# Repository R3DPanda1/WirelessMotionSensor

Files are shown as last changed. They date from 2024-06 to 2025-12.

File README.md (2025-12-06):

# Wireless Motion Sensor

A portable all-in-one motion sensor device with Bluetooth connectivity and SD card data logging capabilities, developed as a Bachelor's thesis project at UAS Technikum Wien.

## Overview

This project presents a low-cost, user-friendly wireless motion tracking device designed for measuring acceleration, rotation, and orientation data at 100 Hz using a Bosch BNO055 IMU sensor. The device features wireless communication between two units, local data storage, and an intuitive OLED display interface.

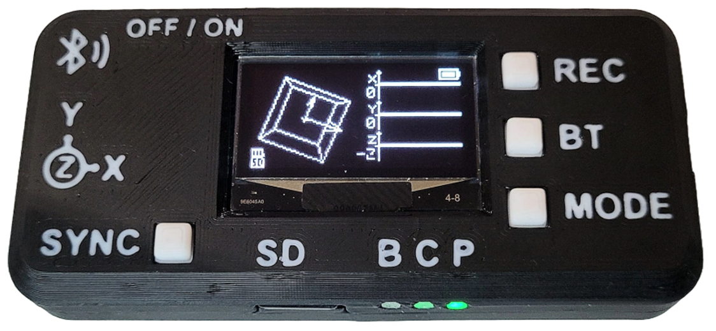
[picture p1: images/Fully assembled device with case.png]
Fully Assembled Device


## Key Features

- **High-Speed Motion Capture**: Measures acceleration, rotation, and orientation at 100 Hz
- **Wireless Communication**: Bluetooth Classic connectivity for real-time data sharing between two devices
- **Data Logging**: SD card storage in CSV format for easy data access
- **Clock Synchronization**: Devices can be synchronized by tapping them together (high-g interrupt method)
- **User-Friendly Interface**: 1.3" OLED display with push-button controls
- **Portable Design**: Battery-powered with 3D-printed snap-fit case
- **Multiple Operation Modes**:
  - Fusion Mode (orientation visualization)
  - Temperature Mode
  - Spirit Level Mode
  - Raw Readings Mode

## Hardware Components

### Main Components
- **Microcontroller**: ESP32-WROOM-32
- **IMU Sensor**: Bosch BNO055 (9-DOF with sensor fusion)
- **Display**: SH1106 1.3" OLED (128x64 pixels)
- **Storage**: MicroSD card slot
- **Power**: Li-Ion/Li-Polymer battery with USB-C charging
- **Connectivity**: Bluetooth Classic

### PCB Design

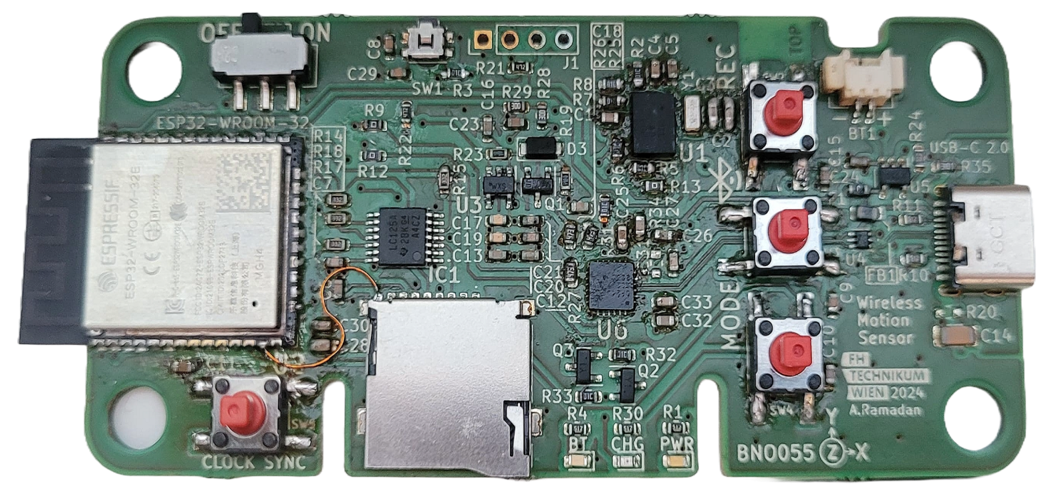
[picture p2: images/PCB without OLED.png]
PCB without OLED

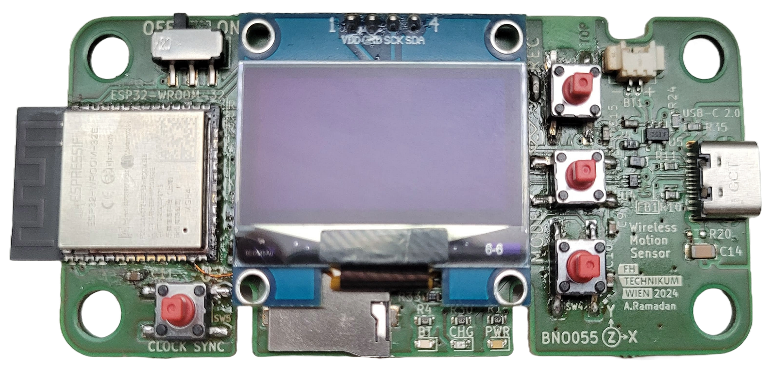
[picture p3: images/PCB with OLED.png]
PCB with OLED


The custom 4-layer PCB features:
- Compact design (96.6mm x 44.4mm x 19.9mm)
- Hand-assembled components
- Compatible with various 0.96" or 1.3" OLED displays
- M5 mounting holes for case integration

### Circuit Schematic

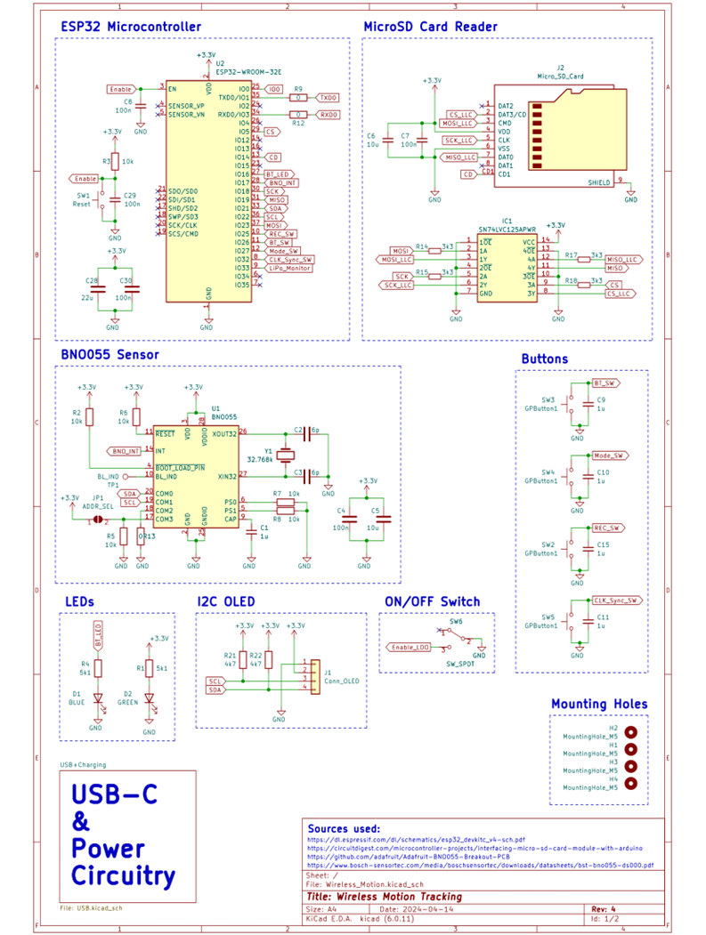
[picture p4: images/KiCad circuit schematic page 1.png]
Circuit Schematic Page 1

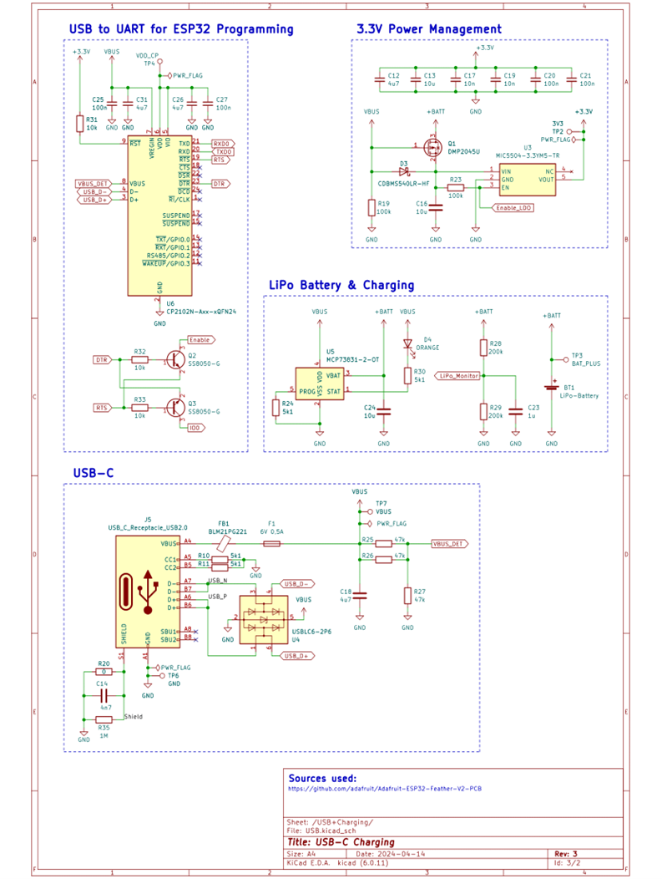
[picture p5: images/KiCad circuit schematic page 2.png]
Circuit Schematic Page 2


## Case Design

The device is housed in a 3D-printed snap-fit case designed in Autodesk Fusion:

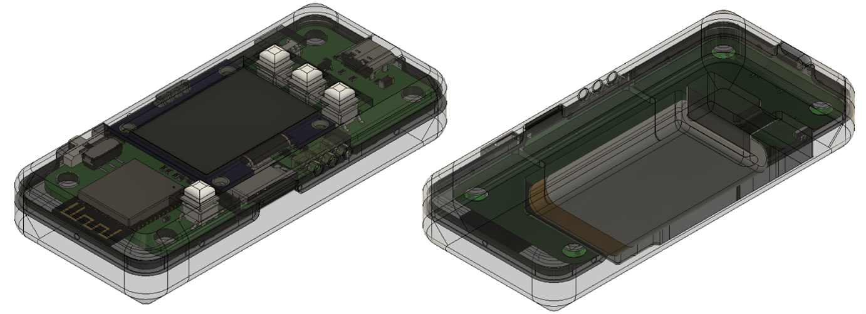
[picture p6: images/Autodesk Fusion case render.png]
Case Render


Features:
- Snap-fit assembly (no screws required)
- Integrated battery compartment
- Button and switch caps
- Multi-material printing support for labeling

## Software Architecture

The firmware uses FreeRTOS with seven concurrent tasks:
- **Button Task**: Handles user input
- **Sensor Task**: Reads IMU data and manages clock synchronization
- **Render Task**: Controls OLED display output
- **Bluetooth TX/RX Tasks**: Manages wireless communication
- **SD Card Task**: Handles file operations
- **CSV Task**: Prepares data for logging with write buffer optimization

### Data Recording

- CSV format for easy accessibility
- Buffered writing to reduce SD card wear
- Simultaneous local and remote data logging
- Timestamp synchronization between devices

## Operation Modes

1. **Fusion Mode**: 3D cube visualization of orientation with linear acceleration graph
2. **Temperature Mode**: Display local and remote temperature readings
3. **Spirit Level Mode**: Digital level indicator with tilt angle
4. **Raw Readings Mode**: Real-time graphs of accelerometer, gyroscope, and magnetometer data
5. **Clock Sync Mode**: Synchronize device clocks by tapping them together

## Getting Started

### Hardware Requirements
- Wireless Motion Sensor device
- MicroSD card (formatted as FAT32)
- Li-Ion or Li-Polymer battery (JST 2.54mm connector)
- USB-C cable for charging and programming

### Basic Usage

1. **Power On**: Slide the ON/OFF switch to ON position
2. **Insert SD Card**: Insert a FAT32-formatted microSD card (optional, for data logging)
3. **Connect Devices**: Press the BT button on one device to establish connection
4. **Select Mode**: Press MODE button to cycle through operation modes
5. **Record Data**: Press REC button to start/stop data logging
6. **Sync Clocks**: Press SYNC button (on master device) and tap devices together

### Controls

- **MODE**: Switch between operation modes
- **BT**: Initiate/disconnect Bluetooth connection
- **REC**: Start/stop CSV data logging
- **SYNC**: Begin clock synchronization process (master device only)

## Performance

- **Synchronization Accuracy**: Typically within 5ms
- **Bluetooth Latency**: ~15ms average
- **Data Rate**: 100 Hz for all sensor readings
- **Packet Loss**: ~24% during simultaneous Bluetooth and SD card operations

## Applications

- Motion capture and tracking
- Sports performance analysis
- Gait analysis and rehabilitation
- Robotics and drone motion tracking
- Joint movement studies
- Vibration analysis

## Development

### Build Environment
- Platform: PlatformIO with Arduino framework
- Language: C/C++
- RTOS: FreeRTOS

### PCB Design
- Tool: KiCad
- Manufacturer: Aisler
- Layers: 4 (Signal, Ground, Power, Signal)

### Mechanical Design
- Tool: Autodesk Fusion
- Manufacturing: 3D printing (FDM)

## Project Structure

```
WirelessMotionSensor/
├── src/                    # Source code
├── include/                # Header files
├── KiCad/                  # PCB design files
├── CAD/                    # 3D case design files
├── images/                 # Documentation images
└── platformio.ini          # PlatformIO configuration
```

## Future Improvements

- Enhanced communication protocol (ESP-NOW) for multiple device support
- Optimized code for better performance
- Additional display interfaces
- Live data logging over USB
- Support for more than two connected devices

## License

This project was developed as a Bachelor's thesis at UAS Technikum Wien.

## Author

**Alper Ramadan**
Bachelor of Science in Engineering - Electronics
UAS Technikum Wien, 2024

Supervisor: Stefan Paschek, MSc

## Acknowledgments

Special thanks to:
- UAS Technikum Wien for providing education and resources
- Jakob Frenzel for PCB design guidance
- Adafruit and AZ-Delivery for open-source hardware designs

## References

Based on the Bachelor's thesis: "Development of a Portable Motion Sensor Device with Bluetooth and SD Card Capabilities"

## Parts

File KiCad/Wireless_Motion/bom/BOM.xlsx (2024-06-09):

Bill of Materials for Two Devices
Mouser Parts
Designator | Value | Footprint | Mouser Part Number | Order Unit Price | Quantity | Total
BT1 | LiPo-Battery | JST 1x02 | 538-53261-0271 | €0.409 | 2 | €0.818
C1,C9,C10,C11,C15,C23 | 1u | 0603 - Inch | 80-C0603C105K4R | €0.039 | 12 | €0.468
C12,C18,C26,C31 | 4u7 | 0603 - Inch | 187-CL10A475KQ8NNNC | €0.094 | 8 | €0.752
C14 | 4n7 | 1206 - Inch | 80-C1206C472K5R7553 | €0.093 | 2 | €0.186
C17,C19 | 10n | 0603 - Inch | 581-06031C103K | €0.094 | 4 | €0.376
C2,C3 | 6p | 0603 - Inch | 80-CBR06C609C5GAUTO | €0.093 | 4 | €0.372
C28 | 22u | 0603 - Inch | 81-GRM188R60J226ME0D | €0.140 | 2 | €0.280
C4,C7,C8,C20,C21,C25,C27,C29,C30 | 100n | 0603 - Inch | 80-C0603C104J5R | €0.051 | 18 | €0.918
C5,C6,C13,C16,C24 | 10u | 0603 - Inch | 187-CL10A106MQ8NNNC | €0.067 | 10 | €0.670
D1 | BLUE | 0603 - Inch | 720-LBQ39GL2N2351 | €0.338 | 2 | €0.676
D2 | GREEN | 0603 - Inch | 720-LTQ39GQ1S22515 | €0.338 | 2 | €0.676
D3 | CDBMS540LR-HF | SOD-123 | 750-CDBMS540LR-HF | €0.363 | 2 | €0.726
D4 | ORANGE | 0603 - Inch | 720-LYQ396P1Q236 | €0.205 | 2 | €0.410
F1 | 6V 0,5A | 0603 - Inch | 603-SMD0603B050TF | €0.188 | 2 | €0.376
FB1 | BLM21PG221 | 0805 - Inch | 81-BLM21P221SG | €0.112 | 2 | €0.224
IC1 | SN74LVC125APWR | SN74LVC125APWR | 595-SN74LVC125APWR | €0.372 | 2 | €0.744
J2 | Micro_SD_Card | Micro SD card connector | 909-MICRO-SD-CARD | €0.512 | 2 | €1.024
J5 | USB_C_Receptacle_USB2.0 | GCT USB4105-xx-A 16P | 640-USB4105-GF-A | €0.752 | 2 | €1.504
Q1 | DMP2045U | SOT-23-3 | 621-DMP2045U-7 | €0.363 | 2 | €0.726
Q2,Q3 | SS8050-G | Package_TO_SOT_SMD:SOT-23 | 750-SS8050-G | €0.130 | 4 | €0.520
R1,R4,R10,R11,R24,R30 | 5k1 | 0603 - Inch | 708-RMCF0603FT5K10 | €0.094 | 12 | €1.128
R14,R15,R17,R18 | 3k3 | 0603 - Inch | 754-RG1608P-332DT5 | €0.093 | 8 | €0.744
R19,R23 | 100k | 0603 - Inch | 667-ERJ-3EKF1003V | €0.094 | 4 | €0.376
R2,R3,R5,R6,R7,R8,R31,R32,R33 | 10k | 0603 - Inch | 603-RT0603FRE0710KL | €0.052 | 18 | €0.936
R21,R22 | 4k7 | 0603 - Inch | 652-CR0603-JW-472ELF | €0.011 | 4 | €0.044
R25,R26,R27 | 47k | 0603 - Inch | 603-RT0603FRE1347RL | €0.093 | 6 | €0.558
R28,R29 | 200k | 0603 - Inch | 603-RC0603FR-07200KL | €0.093 | 4 | €0.372
R35 | 1M | 0603 - Inch | 603-RC0603FR-071ML | €0.094 | 2 | €0.188
R9,R12,R13,R20 | 0 | 0603 - Inch | 603-RC0603FR-070RL | €0.094 | 8 | €0.752
SW1 | Reset | EVQP7 | 667-EVQP7C01P | €0.273 | 2 | €0.546
SW2,SW3,SW4,SW5 | GPButton1 | TL3301 | 612-TL3301SPF260QJ | €0.244 | 8 | €1.952
SW6 | SW_SPDT | SPDT | 611-JS102011SAQN | €0.620 | 2 | €1.240
U1 | BNO055 | BNO055 | 262-BNO055 | €11.460 | 2 | €22.920
U2 | ESP32-WROOM-32E | ESP32-WROOM-32 | 356-ESP32WRM320EH3PS | €2.540 | 2 | €5.080
U3 | MIC5504-3.3YM5-TR | SOT-95 | 998-MIC5504-3.3YM5TR | €0.150 | 2 | €0.300
U4 | USBLC6-2P6 | SOT-666 | 511-USBLC6-2P6 | €0.428 | 2 | €0.856
U5 | MCP73831-2-OT | SOT-23-5 | MCP73831T-2ACI/OT | €0.642 | 2 | €1.284
U6 | CP2102N-Axx-xQFN24 | CP2102 | 634-CP2102NA02QFN24R | €3.220 | 2 | €6.440
Y1 | 32.768k | SMD_3215-2Pin_3.2x1.5mm | 520-.327-12.5-34QCST | €0.911 | 2 | €1.822
 |  |  |  |  | Total: | €59.984
Other Parts
Part | Purchase link |  |  | Order Unit Price | Quantity | Total
OLED Display | https://www.amazon.de/dp/B07V9SLQ6W |  |  | €6.390 | 2 | €12.780
Battery | https://www.amazon.de/dp/B087LTZW61 |  |  | €6.048 | 2 | €12.095
 |  |  |  |  | Total: | €24.875
Aisler PCB Order
Product |  |  |  | Order Unit Price | Order Quantity | Total
Beautiful Board HD 4L |  |  |  | €8.02 | 3 | €24.07
Stellar Stencil |  |  |  | €8.27 | 1 | €8.27
 |  |  |  |  | Total for 3 PCBs: | €32.340
 |  |  | Grand Total for Two Devices (Untaxed) |  |  | €117.199
 |  |  | Grand Total for Two Devices (Taxed 20%) |  |  | €140.639

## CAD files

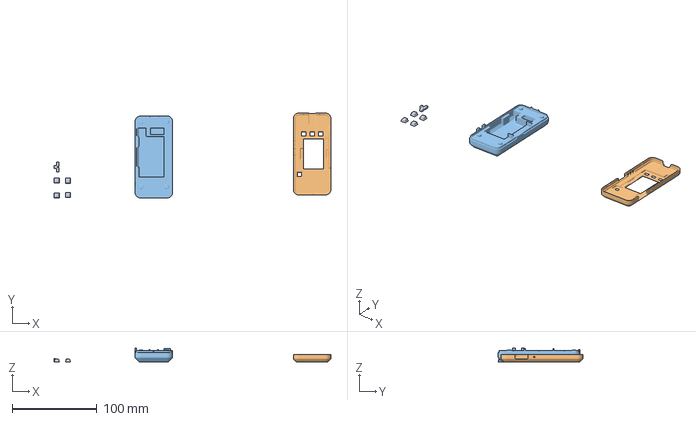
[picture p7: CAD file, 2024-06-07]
3D printed case/Wireless_Motion_Case-Bambu_Studio_Project.3mf
326.1 x 100.1 x 16.3 mm
Assembly x 3

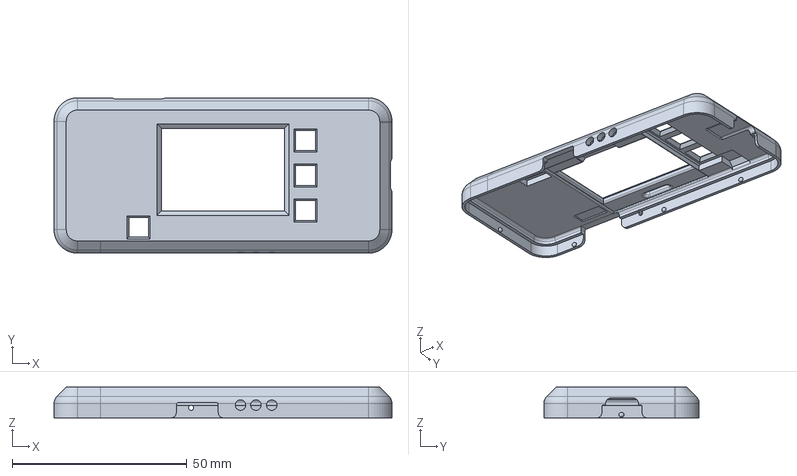
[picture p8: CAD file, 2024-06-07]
3D printed case/Wireless_Motion_Case_Top.step
96.6 x 44.4 x 8.80 mm

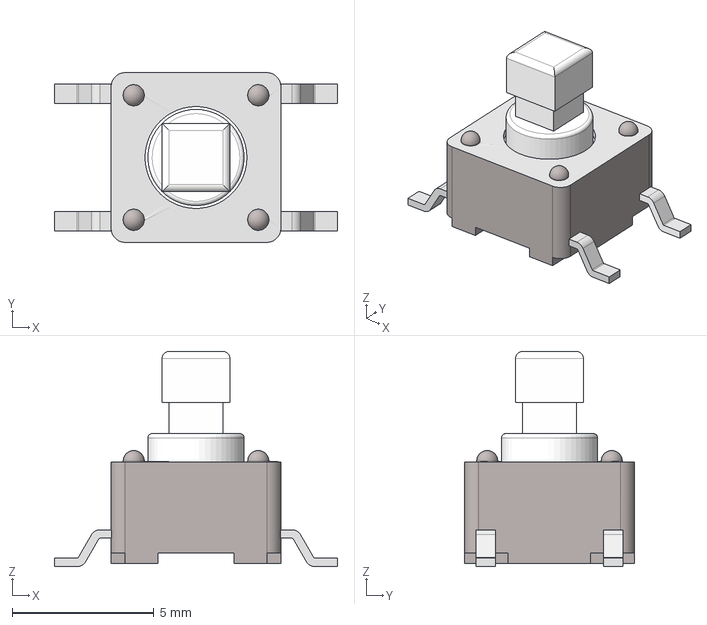
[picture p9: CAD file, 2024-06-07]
KiCad/Wireless_Motion/3D/TL3301TF100QG.stp
10.0 x 6.00 x 7.60 mm

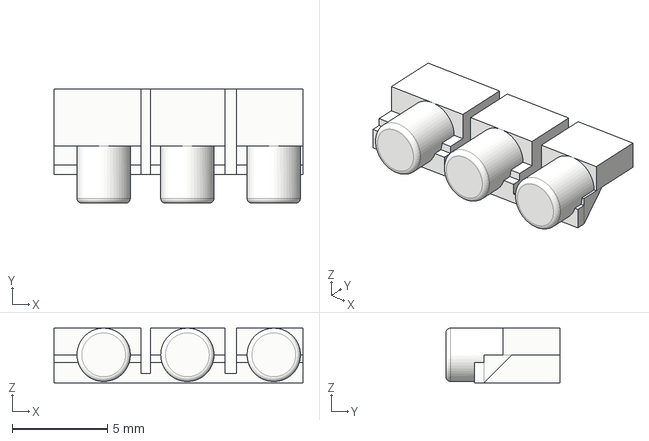
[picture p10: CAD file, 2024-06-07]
3D printed case/Wireless_Motion_Case_LED.step
13.1 x 6.00 x 2.87 mm

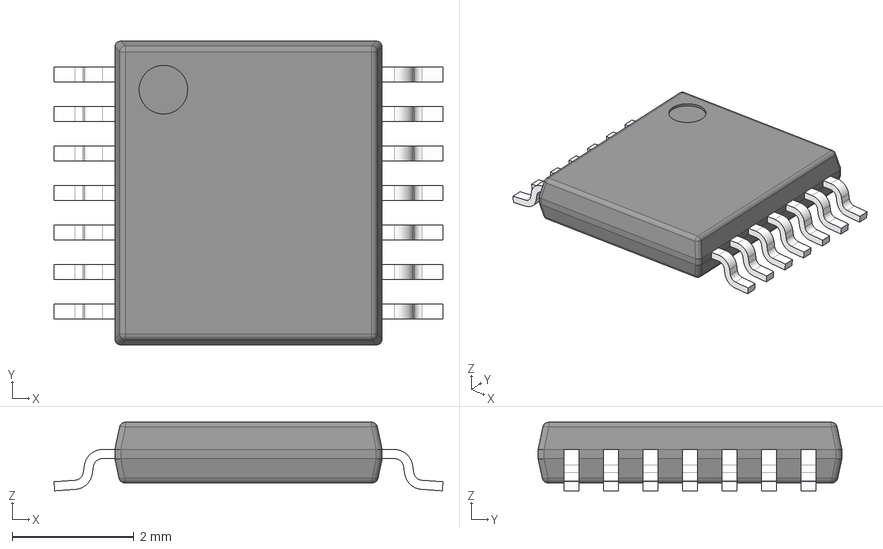
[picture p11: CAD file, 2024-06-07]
KiCad/Wireless_Motion/3D/SN74LVC125APWR.stp
6.40 x 5.00 x 1.13 mm
BODY-TSSOP
LEAD-TSSOP x 14
PIN1

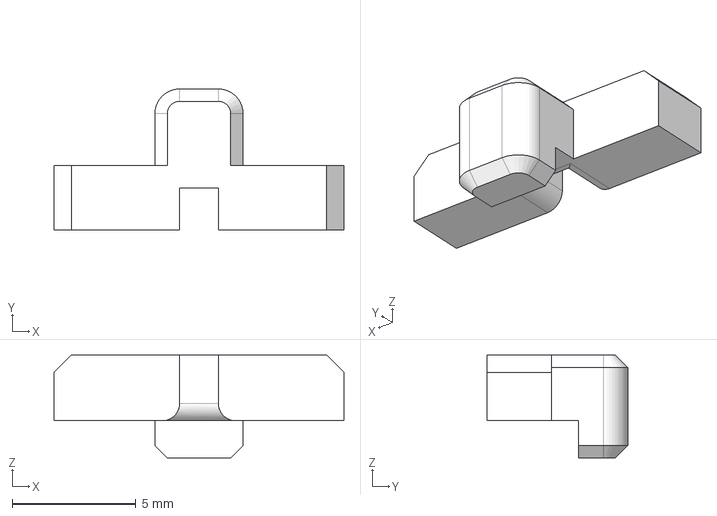
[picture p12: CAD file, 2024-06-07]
3D printed case/Wireless_Motion_Case_Switch.step
11.7 x 5.70 x 4.15 mm

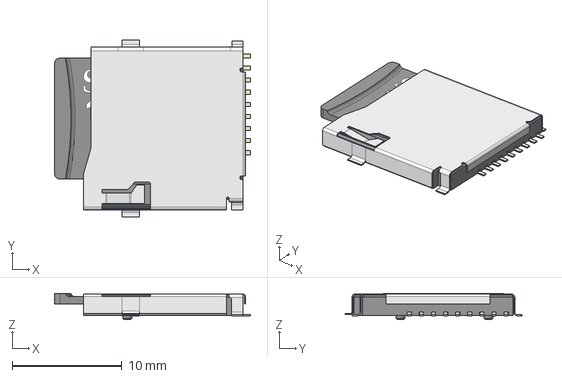
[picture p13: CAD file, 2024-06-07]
KiCad/Wireless_Motion/3D/TF-01A.step
17.8 x 16.1 x 2.40 mm

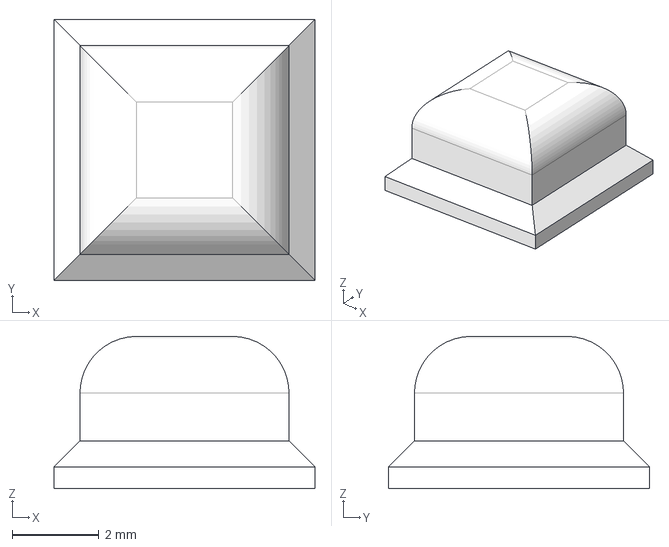
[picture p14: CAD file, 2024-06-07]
3D printed case/Wireless_Motion_Case_Button.step
6.00 x 6.00 x 3.50 mm

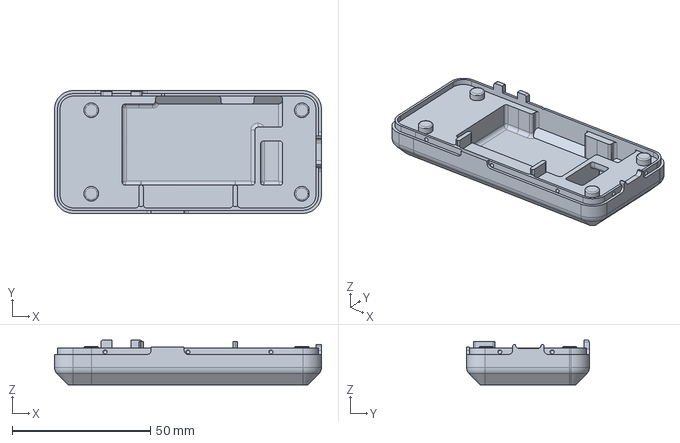
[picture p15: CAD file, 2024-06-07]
3D printed case/Wireless_Motion_Case_Bottom.step
96.6 x 44.4 x 16.3 mm

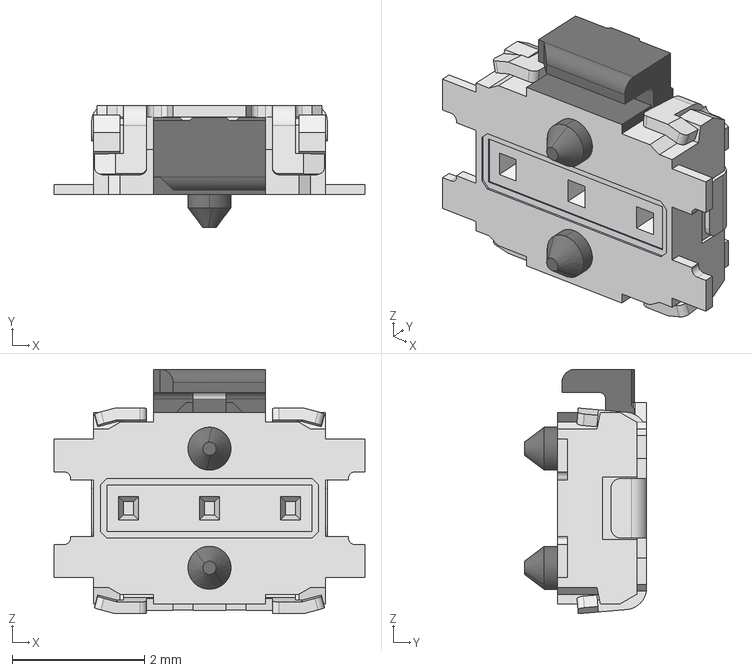
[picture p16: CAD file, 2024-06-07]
KiCad/Wireless_Motion/3D/EVQP7-LC-01P-1.STEP
4.70 x 1.85 x 3.69 mm

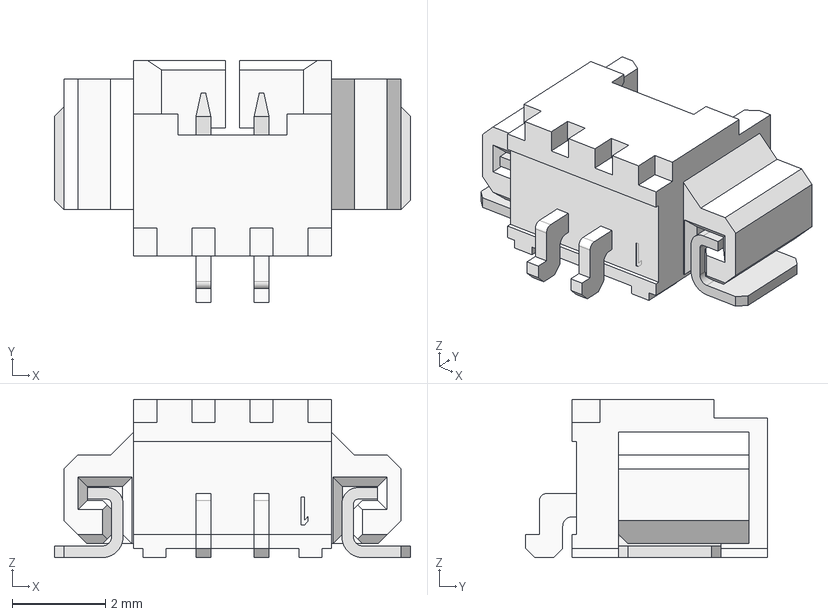
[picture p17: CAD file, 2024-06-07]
KiCad/Wireless_Motion/3D/53261-0271.stp
7.65 x 5.20 x 3.40 mm

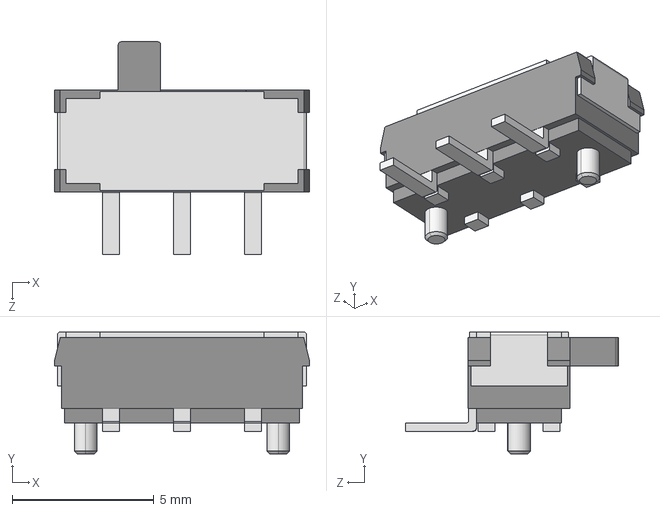
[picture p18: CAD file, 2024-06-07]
KiCad/Wireless_Motion/3D/JS102011SAQN.STEP
9.00 x 4.30 x 7.50 mm

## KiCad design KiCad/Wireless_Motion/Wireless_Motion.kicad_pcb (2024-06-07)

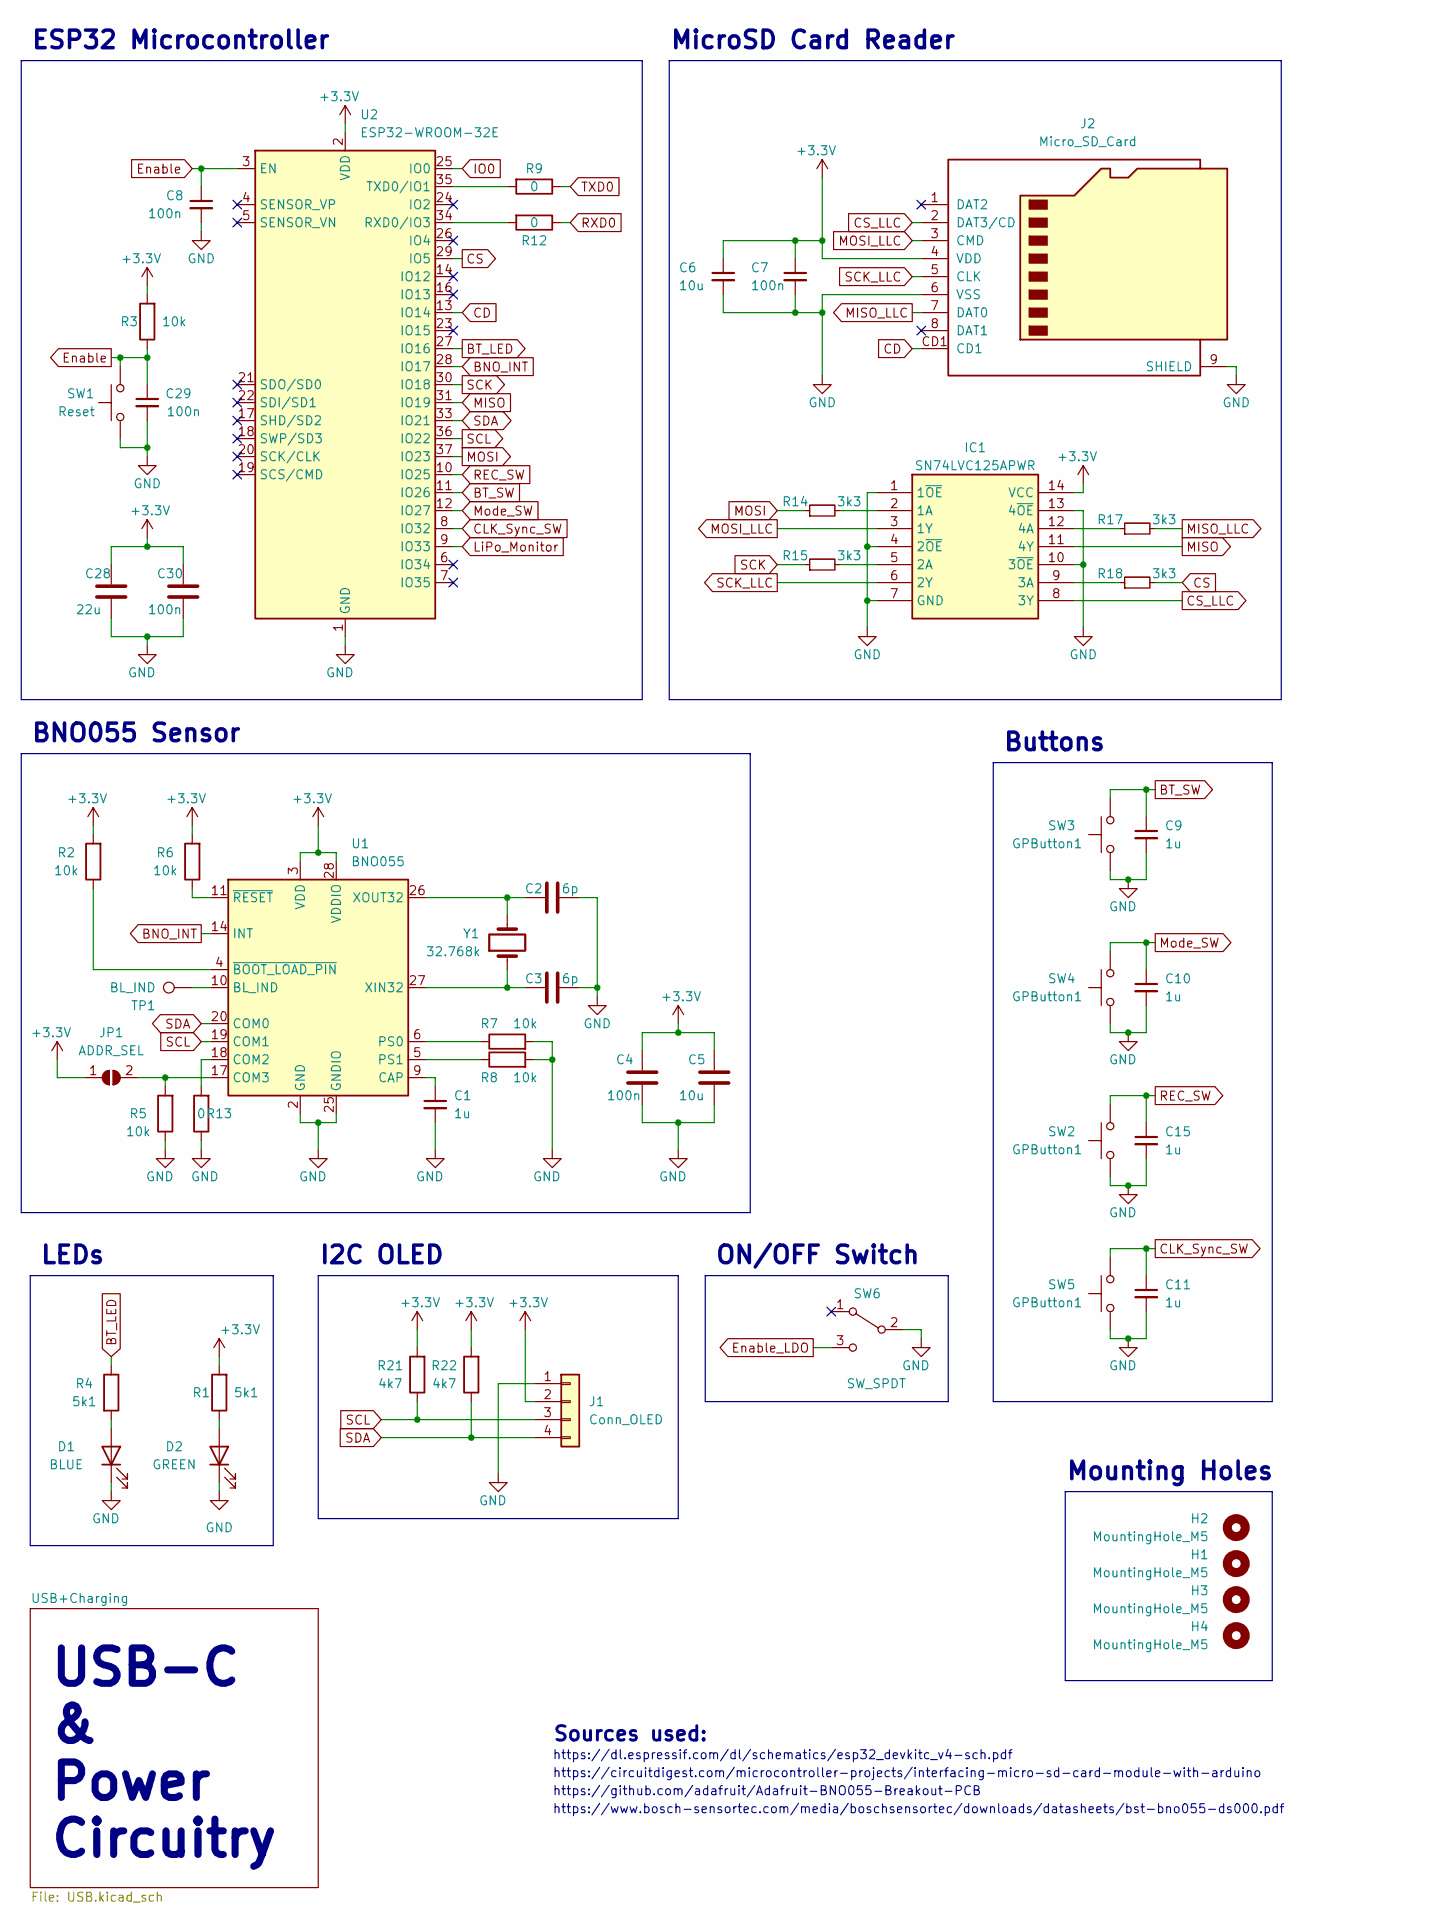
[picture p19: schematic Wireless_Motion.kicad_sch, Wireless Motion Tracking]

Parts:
C1, C9, C10, C11, C15: 1u; C_0603_1608Metric
C2, C3: 6p; C_0603_1608Metric; Mouser Part Number 80-CBR06C609C5GAUTO
C4, C7, C8, C29, C30: 100n; C_0603_1608Metric
C5, C6: 10u; C_0603_1608Metric
C28: 22u; C_0603_1608Metric
D1: BLUE; LED_0603_1608Metric; Mouser Part Number 720-LBQ39GL2N2351
D2: GREEN; LED_0603_1608Metric; Mouser Part Number 720-LTQ39GQ1S22515
H1, H2, H3, H4: MountingHole_M5; MountingHole_5.3mm_M5_DIN965
IC1: SN74LVC125APWR; Mouser Part Number 595-SN74LVC125APWR
J1: Conn_OLED; PinHeader_1x04_P2.54mm_Vertical
J2: Micro_SD_Card; MICROSDCARD; Mouser Part Number 909-MICRO-SD-CARD
JP1: ADDR_SEL; SolderJumper-2_P1.3mm_Open_TrianglePad1.0x1.5mm
R1, R4: 5k1; R_0603_1608Metric
R2, R3, R5, R6, R7, R8: 10k; R_0603_1608Metric
R9, R12, R13: 0; R_0603_1608Metric
R14, R15, R17, R18: 3k3; R_0603_1608Metric
R21, R22: 4k7; R_0603_1608Metric
SW1: Reset; SW_SPST_EVQP7C; Mouser Part Number 667-EVQP7C01P
SW2, SW3, SW4, SW5: GPButton1; TL3301TF100QG; Mouser Part Number 612-TL3301SPF260QJ
SW6: SW_SPDT; SW_SPDT_CK-JS102011SAQN; Mouser Part Number 611-JS102011SAQN
TP1: BL_IND; TestPoint_Pad_D1.0mm
U1: BNO055; LGA-28_5.2x3.8mm_P0.5mm; Mouser Part Number 262-BNO055
U2: ESP32-WROOM-32E; ESP32-WROOM-32; Mouser Part Number 356-ESP32WRM320EH3PS
Y1: 32.768k; Crystal_SMD_3215-2Pin_3.2x1.5mm; Mouser Part Number 520-.327-12.5-34QCST

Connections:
+3.3V: C4.1, C5.1, C6.1, C7.1, C28.1, C30.1, IC1.14 (VCC), J1.2, J2.4 (VDD), JP1.1 (A), R1.2, R2.2, R3.2, R6.2, R21.2, R22.2, U1.3 (VDD), U1.28 (VDDIO), U2.2 (VDD); also elsewhere on the board
BNO_INT: U1.14 (INT), U2.28 (IO17)
BT_LED: R4.1, U2.27 (IO16)
BT_SW: C9.1, SW3.1, U2.11 (IO26)
CD: J2.CD1, U2.13 (IO14)
CLK_Sync_SW: C11.1, SW5.1, U2.8 (IO32)
CS: R18.2, U2.29 (IO5)
CS_LLC: IC1.8 (3Y), J2.2 (DAT3/CD)
Enable: C8.1, C29.1, R3.1, SW1.1, U2.3 (EN); also elsewhere on the board
Enable_LDO: SW6.3 (C); also elsewhere on the board
GND: C1.2, C2.2, C3.2, C4.2, C5.2, C6.2, C7.2, C8.2, C9.2, C10.2, C11.2, C15.2, C28.2, C29.2, C30.2, D1.1 (K), D2.1 (K), IC1.1 (1~OE), IC1.4 (2~OE), IC1.7 (GND), IC1.10 (3~OE), IC1.13 (4~OE), J1.1, J2.6 (VSS), J2.9 (SHIELD), R5.1, R7.2, R8.2, R13.1, SW1.2, SW2.2, SW3.2, SW4.2, SW5.2, SW6.2 (B), U1.2 (GND), U1.15 (GNDIO), U1.16 (GNDIO), U1.25 (GNDIO), U2.1 (GND), U2.15 (GND), U2.38 (GND), U2.39 (GND); also elsewhere on the board
IO0: U2.25 (IO0); also elsewhere on the board
LiPo_Monitor: U2.9 (IO33); also elsewhere on the board
MISO: IC1.11 (4Y), U2.31 (IO19)
MISO_LLC: J2.7 (DAT0), R17.2
MOSI: R14.1, U2.37 (IO23)
MOSI_LLC: IC1.3 (1Y), J2.3 (CMD)
Mode_SW: C10.1, SW4.1, U2.12 (IO27)
unnamed: C1.1, U1.9 (CAP)
unnamed: C2.1, U1.26 (XOUT32), Y1.2
unnamed: C3.1, U1.27 (XIN32), Y1.1
unnamed: D1.2 (A), R4.2
unnamed: D2.2 (A), R1.1
unnamed: IC1.2 (1A), R14.2
unnamed: IC1.5 (2A), R15.2
unnamed: IC1.9 (3A), R18.1
unnamed: IC1.12 (4A), R17.1
unnamed: JP1.2 (B), R5.2, U1.17 (COM3)
unnamed: R2.1, U1.4 (~BOOT_LOAD_PIN)
unnamed: R6.1, U1.11 (~RESET)
unnamed: R7.1, U1.6 (PS0)
unnamed: R8.1, U1.5 (PS1)
unnamed: R9.2, U2.35 (TXD0/IO1)
unnamed: R12.2, U2.34 (RXD0/IO3)
unnamed: R13.2, U1.18 (COM2)
unnamed: TP1.1, U1.10 (BL_IND)
REC_SW: C15.1, SW2.1, U2.10 (IO25)
RXD0: R12.1; also elsewhere on the board
SCK: R15.1, U2.30 (IO18)
SCK_LLC: IC1.6 (2Y), J2.5 (CLK)
SCL: J1.3, R21.1, U1.19 (COM1), U2.36 (IO22)
SDA: J1.4, R22.1, U1.20 (COM0), U2.33 (IO21)
TXD0: R9.1; also elsewhere on the board

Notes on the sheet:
I2C OLED
https://www.bosch-sensortec.com/media/boschsensortec/downloads/datasheets/bst-bno055-ds000.pdf
Buttons
ON/OFF Switch
MicroSD Card Reader
Mounting Holes
https://circuitdigest.com/microcontroller-projects/interfacing-micro-sd-card-module-with-arduino
Sources used:
ESP32 Microcontroller
https://dl.espressif.com/dl/schematics/esp32_devkitc_v4-sch.pdf
https://github.com/adafruit/Adafruit-BNO055-Breakout-PCB
BNO055 Sensor
USB-C & Power Circuitry
LEDs

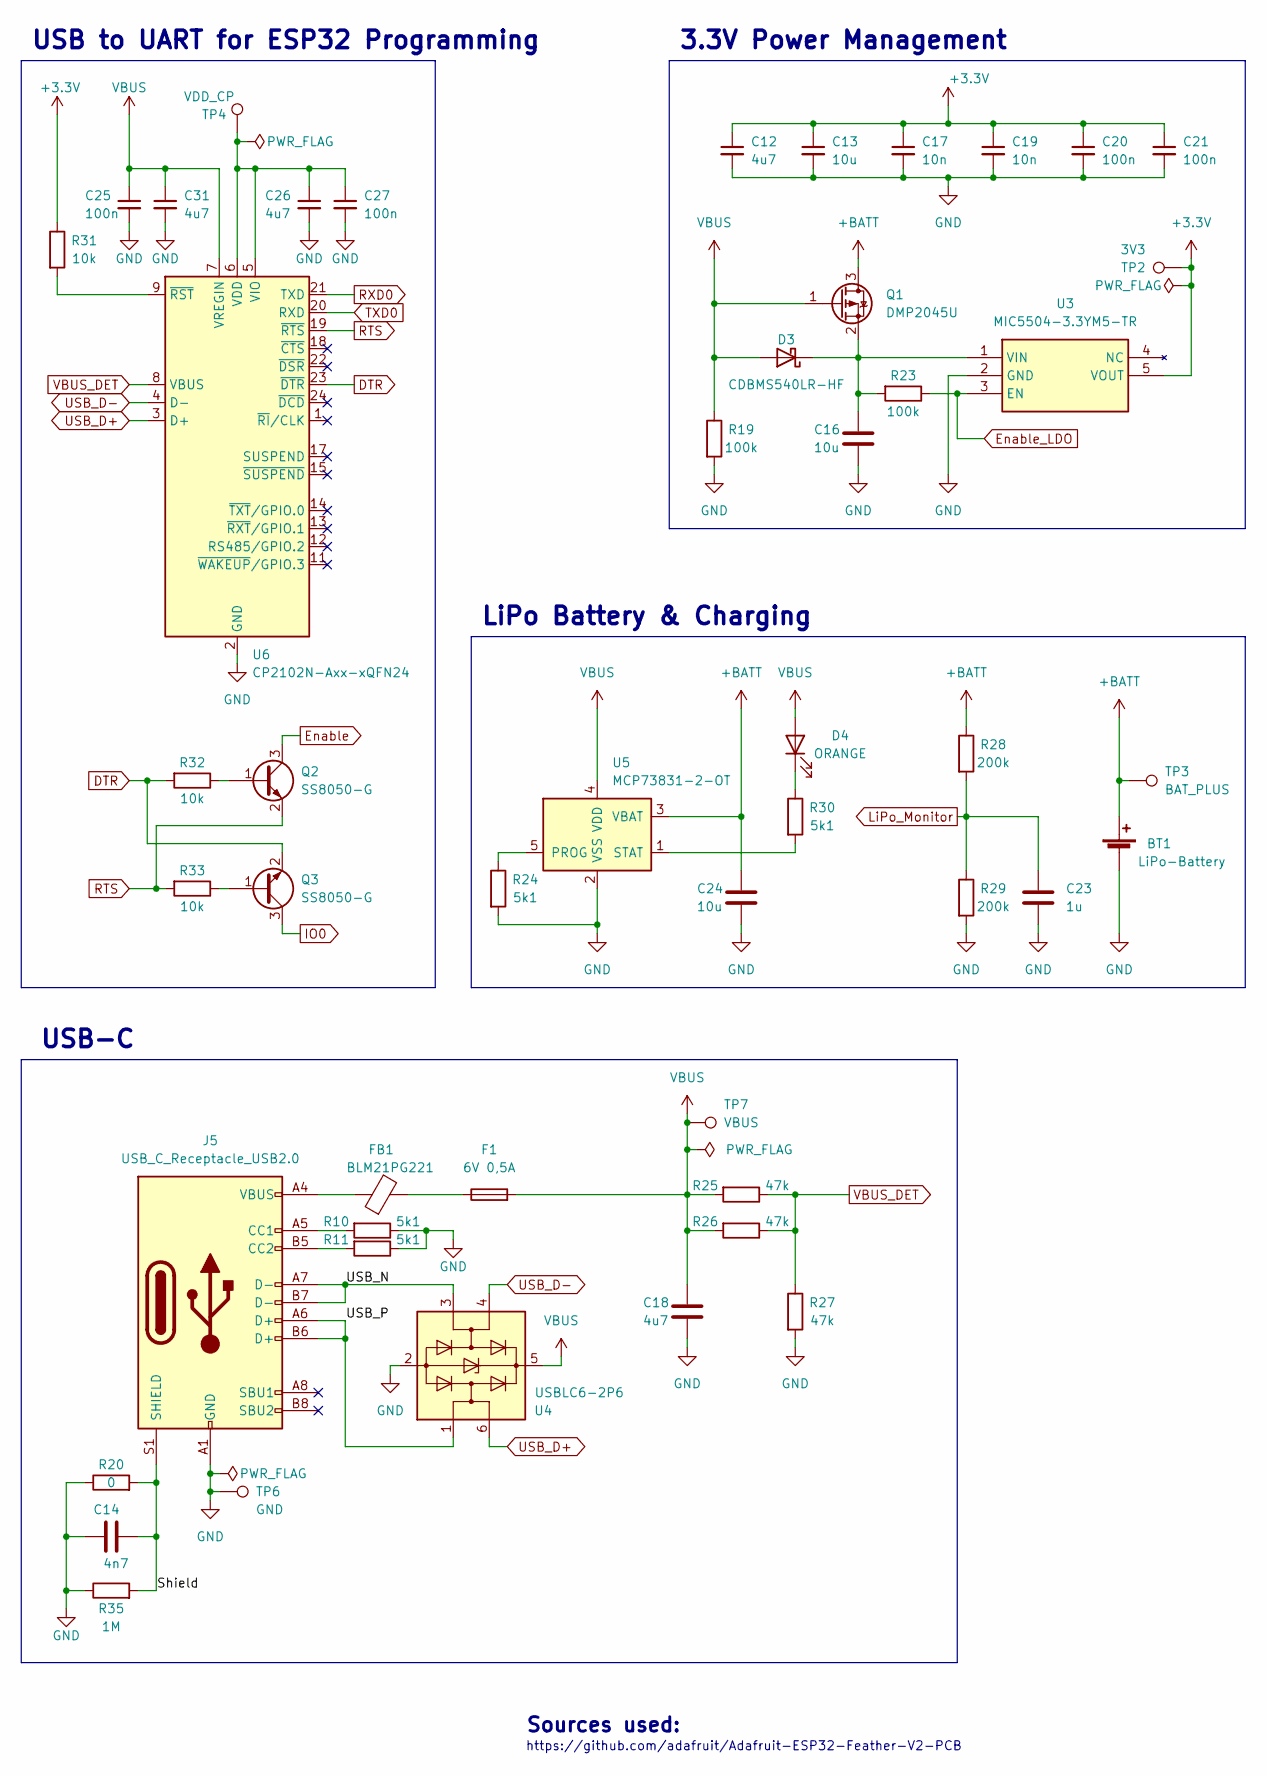
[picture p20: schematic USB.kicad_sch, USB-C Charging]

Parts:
BT1: LiPo-Battery; JST_1x02_Horizontal; Mouser Part Number 538-53261-0271
C12, C18, C26, C31: 4u7; C_0603_1608Metric
C13, C16, C24: 10u; C_0603_1608Metric
C14: 4n7; C_1206_3216Metric; Mouser Part Number 80-C1206C472K5R7553
C17, C19: 10n; C_0603_1608Metric
C20, C21, C25, C27: 100n; C_0603_1608Metric
C23: 1u; C_0603_1608Metric
D3: CDBMS540LR-HF; D_SOD-123; Mouser Part Number 750-CDBMS540LR-HF
D4: ORANGE; LED_0603_1608Metric; Mouser Part Number 720-LYQ396P1Q236
F1: 6V 0,5A; Fuse_0603_1608Metric; Mouser Part Number 603-SMD0603B050TF
FB1: BLM21PG221; L_0805_2012Metric; Mouser Part Number 81-BLM21P221SG
J5: USB_C_Receptacle_USB2.0; USB_C_Receptacle_GCT_USB4105-xx-A_16P_TopMnt_Horizontal; Mouser Part Number 640-USB4105-GF-A
Q1: DMP2045U; SOT-23-3; Mouser Part Number 621-DMP2045U-7
Q2, Q3: SS8050-G; SOT-23; Mouser Part Number 750-SS8050-G
R10, R11, R24, R30: 5k1; R_0603_1608Metric
R19, R23: 100k; R_0603_1608Metric
R20: 0; R_0603_1608Metric
R25, R26, R27: 47k; R_0603_1608Metric
R28, R29: 200k; R_0603_1608Metric
R31, R32, R33: 10k; R_0603_1608Metric
R35: 1M; R_0603_1608Metric
TP2: 3V3; TestPoint_Pad_D2.0mm
TP3: BAT_PLUS; TestPoint_Pad_D2.0mm
TP4: VDD_CP; TestPoint_Pad_D1.0mm
TP6: GND; TestPoint_Pad_D2.0mm
TP7: VBUS; TestPoint_Pad_D2.0mm
U3: MIC5504-3.3YM5-TR; SOT95P280X145-5N; Mouser Part Number 998-MIC5504-3.3YM5TR
U4: USBLC6-2P6; SOT-666; Mouser Part Number 511-USBLC6-2P6
U5: MCP73831-2-OT; SOT-23-5; Mouser Part Number MCP73831T-2ACI/OT
U6: CP2102N-Axx-xQFN24; QFN-24-1EP_4x4mm_P0.5mm_EP2.6x2.6mm; Mouser Part Number 634-CP2102NA02QFN24R

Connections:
+3.3V: C12.1, C13.1, C17.1, C19.1, C20.1, C21.1, R31.1, TP2.1, U3.5 (VOUT); also elsewhere on the board
+BATT: BT1.1 (+), C24.1, Q1.3 (D), R28.1, TP3.1, U5.3 (VBAT)
/USB+Charging/Shield: C14.2, J5.S1 (SHIELD), R20.2, R35.2
/USB+Charging/USB_N: J5.A7 (D-), J5.B7 (D-), U4.3 (I/O2)
/USB+Charging/USB_P: J5.A6 (D+), J5.B6 (D+), U4.1 (I/O1)
DTR: Q3.2 (E), R32.2, U6.23 (~DTR)
Enable: Q2.3 (C); also elsewhere on the board
Enable_LDO: R23.1, U3.3 (EN); also elsewhere on the board
GND: BT1.2 (-), C12.2, C13.2, C14.1, C16.2, C17.2, C18.2, C19.2, C20.2, C21.2, C23.2, C24.2, C25.2, C26.2, C27.2, C31.2, J5.A1 (GND), J5.A12 (GND), J5.B1 (GND), J5.B12 (GND), R10.1, R11.1, R19.2, R20.1, R24.2, R27.2, R29.2, R35.1, TP6.1, U3.2 (GND), U4.2 (GND), U5.2 (VSS), U6.2 (GND), U6.25 (GND); also elsewhere on the board
IO0: Q3.3 (C); also elsewhere on the board
LiPo_Monitor: C23.1, R28.2, R29.1; also elsewhere on the board
unnamed: C16.1, D3.1 (K), Q1.2 (S), R23.2, U3.1 (VIN)
unnamed: D4.1 (K), R30.1
unnamed: F1.1, FB1.2
unnamed: FB1.1, J5.A4 (VBUS), J5.A9 (VBUS), J5.B4 (VBUS), J5.B9 (VBUS)
unnamed: J5.A5 (CC1), R10.2
unnamed: J5.B5 (CC2), R11.2
unnamed: Q2.1 (B), R32.1
unnamed: Q3.1 (B), R33.1
unnamed: R24.1, U5.5 (PROG)
unnamed: R30.2, U5.1 (STAT)
unnamed: R31.2, U6.9 (~RST)
unnamed: C26.1, C27.1, TP4.1, U6.5 (VIO), U6.6 (VDD)
RTS: Q2.2 (E), R33.2, U6.19 (~RTS)
RXD0: U6.21 (TXD); also elsewhere on the board
TXD0: U6.20 (RXD); also elsewhere on the board
USB_D+: U4.6 (I/O1), U6.3 (D+)
USB_D-: U4.4 (I/O2), U6.4 (D-)
VBUS: C18.1, C25.1, C31.1, D3.2 (A), D4.2 (A), F1.2, Q1.1 (G), R19.1, R25.2, R26.2, TP7.1, U4.5 (VBUS), U5.4 (VDD), U6.7 (VREGIN)
VBUS_DET: R25.1, R26.1, R27.1, U6.8 (VBUS)

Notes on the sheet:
Sources used:
https://github.com/adafruit/Adafruit-ESP32-Feather-V2-PCB
USB-C
LiPo Battery & Charging
USB to UART for ESP32 Programming
3.3V Power Management

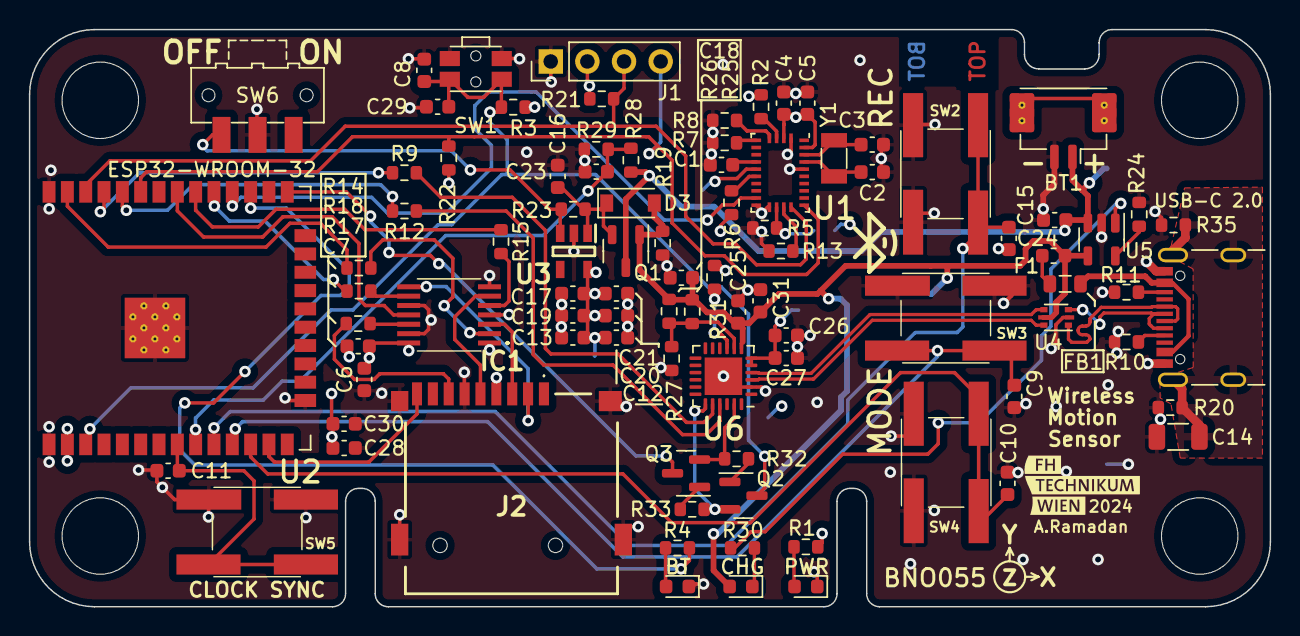
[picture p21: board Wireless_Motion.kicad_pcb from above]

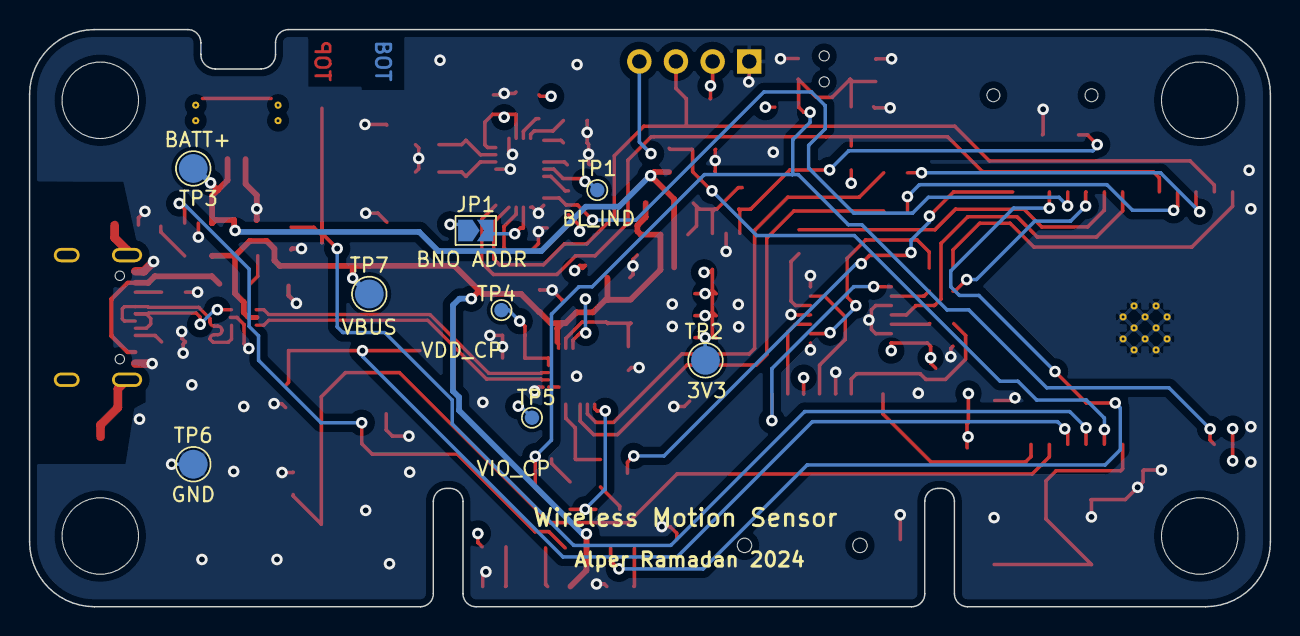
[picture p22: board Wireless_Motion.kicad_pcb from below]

Board: 4 copper layers, 86.0 x 40.0 mm, 102 parts (8 on the bottom side), 65 nets.

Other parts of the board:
TP5: VIO_CP; TestPoint_Pad_D1.0mm

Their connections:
+3.3V: TP5.1; also elsewhere on the board

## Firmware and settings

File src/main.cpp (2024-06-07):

#include <main.h>

void setup()
{
  Serial.begin(115200);
  // Create the button task
  xTaskCreate(sensorTask, "SensorTask", 2048, NULL, 6, &sensorTaskHandle);
  xTaskCreate(bluetoothTXTask, "BluetoothTXTask", 4096, &SerialBT, 3, &bluetoothTXTaskHandle);
  xTaskCreate(bluetoothRXTask, "BluetoothRXTask", 2048, &SerialBT, 5, &bluetoothRXTaskHandle);
  xTaskCreate(buttonTask, "ButtonTask", 1024, NULL, 0, &buttonTaskHandle);
  xTaskCreate(sdCardTask, "SDCardTask", 4096, NULL, 2, &sdCardTaskHandle);
  xTaskCreate(renderTask, "RenderTask", 4096, NULL, 1, &renderTaskHandle);

  localImuSemaphore = xSemaphoreCreateBinary();
  remoteImuSemaphore = xSemaphoreCreateBinary();
  xSemaphoreGive(localImuSemaphore);
  xSemaphoreGive(remoteImuSemaphore);
}

void loop()
{
  vTaskDelete(NULL);
  vTaskDelay(100 / portTICK_PERIOD_MS);
}

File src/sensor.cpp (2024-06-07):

#include "sensor.h"

TaskHandle_t sensorTaskHandle = NULL;
Adafruit_BNO055 bno = Adafruit_BNO055(55, 0x28);
bool calibrationSaved = false;

void readSensor();

// Function to write an 8-bit value to a register
bool writeBNO(uint8_t reg, uint8_t value)
{
    Wire.beginTransmission(BNO055_ADDRESS);
    Wire.write(reg);                    // Register address
    Wire.write(value);                  // Value to write
    return Wire.endTransmission() == 0; // Return true if successful
}

// Function to read an 8-bit value from a register
uint8_t readBNO(uint8_t reg)
{
    uint8_t value = 0;
    Wire.beginTransmission(BNO055_ADDRESS);
    Wire.write(reg);                                       // Register address
    Wire.endTransmission(false);                           // Send restart condition
    Wire.requestFrom((uint8_t)BNO055_ADDRESS, (uint8_t)1); // Request 1 byte
    if (Wire.available())
    {
        value = Wire.read(); // Read the byte
    }
    return value;
}

void saveCalibrationData()
{
    uint8_t calData[22];
    // Read calibration data
    bno.getSensorOffsets(calData);

    // Save calibration data
    for (int i = 0; i < 22; i++)
    {
        EEPROM.write(i, calData[i]);
    }

    // Commit changes to EEPROM
    EEPROM.commit();
    // displayNotification("Calibration saved");
}

void loadCalibrationData()
{
    uint8_t calData[22];

    // Read calibration data from EEPROM
    for (int i = 0; i < 22; i++)
    {
        calData[i] = EEPROM.read(i);
    }

    // Load calibration data
    bno.setSensorOffsets(calData);
    // displayNotification("Calibration load");
}

void configureHighGInterrupt()
{
    bno.setMode(OPERATION_MODE_CONFIG);

    // clear previous interrupt
    (void)readBNO(INT_STA);
    writeBNO(Adafruit_BNO055::BNO055_SYS_TRIGGER_ADDR, 0b01000000);

    writeBNO(Adafruit_BNO055::BNO055_PAGE_ID_ADDR, 1);
    writeBNO(INT_MASK_ADDR, 0b00100000);
    writeBNO(INT_ADDR, 0b00100000);

    writeBNO(ACCEL_INT_SETTINGS_ADDR, 0b11100000);

    writeBNO(ACCEL_HIGH_G_THRES_ADDR, 80);
    writeBNO(ACCEL_HIGH_G_DURN_ADDR, 0);

    writeBNO(Adafruit_BNO055::BNO055_PAGE_ID_ADDR, 0);

    // Serial.println(readBNO(UNIT_SEL),BIN); //check units

    // writeBNO(TEMP_SOURCE, 0b00000001); //choose the gyro temperature sensor
    // writeBNO(UNIT_SEL, 0b10010000); //get Fahrenheit

    bno.setMode(OPERATION_MODE_NDOF);
}

void clearInterrupt()
{
    bno.setMode(OPERATION_MODE_CONFIG);

    // clear previous interrupt
    (void)readBNO(INT_STA);
    writeBNO(Adafruit_BNO055::BNO055_SYS_TRIGGER_ADDR, 0b01000000);

    bno.setMode(OPERATION_MODE_NDOF);
}

void sensorTask(void *pvParameters)
{
    if (!bno.begin()) // generates some errors: [Wire.cpp:499] requestFrom(): i2cWriteReadNonStop returned Error -1
    {
        Serial.println(F("No BNO055 detected... Check wiring or I2C ADDR!"));
        vTaskDelete(NULL);
    }

    /* Use external crystal for better accuracy */
    // bno.setExtCrystalUse(true);

    // int delayAmount = 10;
    TickType_t xFrequency = pdMS_TO_TICKS(10); // Convert 10 ms to ticks (100 Hz)
    TickType_t xLastWakeTime = xTaskGetTickCount();
    unsigned long sync_timeout_time = 0;

    loadCalibrationData();

    for (;;)
    {
        // Save wakeup time
        xLastWakeTime = xTaskGetTickCount();

        if (calibrationSaved == false && millis() >= CALIBRATION_SAVE_TIME)
        {
            saveCalibrationData();
            calibrationSaved = true;
        }

        if (currentOperationMode == MODE_CLK_SYNC)
        {
            if (currentBluetoothMode == MODE_CONNECTED)
            {
                if (currentSyncMode == MODE_SYNC_START)
                {
                    displayNotification("Sync started");
                    configureHighGInterrupt();
                    while (digitalRead(HIGH_G_INT_PIN) == HIGH)
                    {
                        clearInterrupt();
                        delay(100);
                    }
                    attachInterrupt(HIGH_G_INT_PIN, clk_sync_isr, RISING);
                    sync_timeout_time = millis() + SYNC_TIMEOUT;
                    currentSyncMode = MODE_WAIT_HIGH_G;
                }
                if (currentSyncMode == MODE_RETRY)
                {
                    clearInterrupt();
                    while (digitalRead(HIGH_G_INT_PIN) == HIGH)
                    {
                        clearInterrupt();
                        delay(100);
                    }
                    attachInterrupt(HIGH_G_INT_PIN, clk_sync_isr, RISING);
                    sync_timeout_time = millis() + SYNC_TIMEOUT;
                    currentSyncMode = MODE_WAIT_HIGH_G;
                }
                // Wait for interrupt with a timeout
                while (currentSyncMode == MODE_WAIT_HIGH_G && millis() < sync_timeout_time)
                {
                    delay(100);
                }
                switch (currentSyncMode)
                {
                case MODE_WAIT_HIGH_G: // Still waiting after timeout
                    displayNotification("Sync failed");
                    currentSyncMode = MODE_IDLE;
                    detachInterrupt(HIGH_G_INT_PIN);
                    currentOperationMode = MODE_FUSION;
                    break;
                case MODE_HIGH_G_DETECTED:
                {
                    if (btRole == MASTER)
                    {
                        // check if the remote device was synced roughly at the same time
                        unsigned long remoteTime = remoteImuDataGL.timestamp;
                        unsigned long localTime = syncedMillis();
                        unsigned long timeDiff;
                        if (localTime > remoteTime)
                        {
                            timeDiff = localTime - remoteTime;
                        }
                        else
                        {
                            timeDiff = remoteTime - localTime;
                        }
                        if (timeDiff < SYNC_BT_TOLERANCE)
                        {
                            currentSyncMode = MODE_SYNC_SUCCESS;
                        }
                        else
                        {
                            displayNotification("Try again!");
                            currentSyncMode = MODE_RETRY;
                        }
                    }
                    else
                    {
                        displayNotification("Hit!");
                        currentSyncMode = MODE_RETRY;
                    }
                    break;
                }
                case MODE_SYNC_SUCCESS:
                    displayNotification("Synced!");
                    currentSyncMode = MODE_IDLE;
                    detachInterrupt(HIGH_G_INT_PIN);
                    currentOperationMode = MODE_FUSION;
                    break;
                }
            }
            else
            {
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

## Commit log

2024-05-01 less code by using imu namespace
2024-05-07 fixed bt, added more graphics
    [bluetooth.cpp, commons.h, rendering.cpp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]
2024-05-07 mode changing and bt fixes
    [bluetooth.cpp, commons.h, rendering.cpp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]
2024-05-18 battery icom
2024-05-18 battery icon improvement
2024-05-22 relative rotatio correctly implemented
    [bluetooth.cpp, commons.h, main.cpp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]
2024-06-07 IMU data semaphores
2024-06-07 KiCad files
    [53261-0271.stp, BOM.xlsx, EVQP7-LC-01P-1.STEP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]
2024-06-07 3D printed case files
    [Wireless_Motion_Case-Bambu_Studio_Project.3mf, Wireless_Motion_Case_Bottom.step, Wireless_Motion_Case_Button.step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]
2024-06-09 added comments
    [BOM.xlsx]
